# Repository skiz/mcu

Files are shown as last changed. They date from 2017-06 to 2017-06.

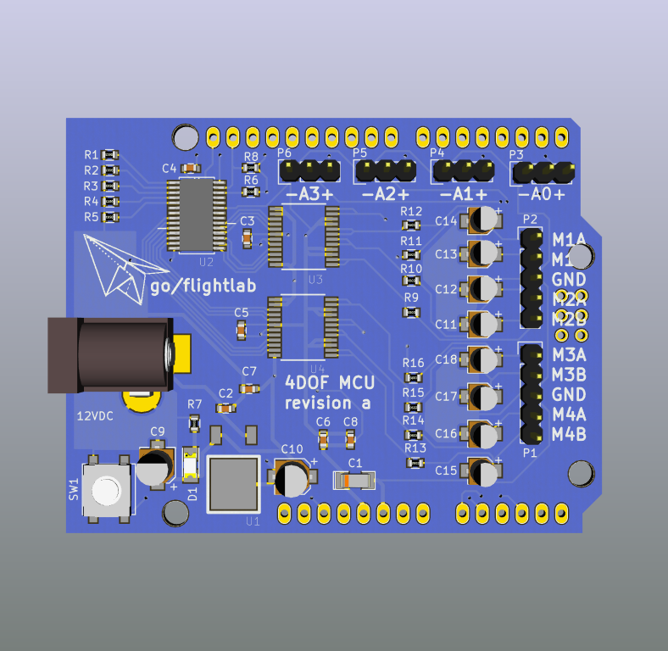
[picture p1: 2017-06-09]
renders/MCU.png

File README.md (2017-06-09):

Motor Control Unit
==================

Overview
--------
This hardware project is based on several existing Arduino boards,
and shields, combining them along with some additional hardware to
provide clean bipolar 10vdc control of up to 3 industrial motor
control units for use with the [SMC3](https://github.com/SimulatorMotorController) 
motion platform software available on Github.

The SMC3 software suite is specifically designed to interact with 
[SimTools](https://www.xsimulator.net/) which generates motion queues
from existing simulator integrations running on Windows.

The schematic, PCB, and related files have been exclusively created in [KiCad](kicad-pcb.org/).

Structure
---------
There are several directories which contain various references for the project;

* board      - The KiCad project itself: PCB, Schematic, etc.
* bom        - Bill of Materials required to assemble the complete PCB.
* datasheets - All datasheets related to the componented used in the design.
* libraries  - Libraries specific to this design (PCB footprints & Symbols).
* models     - 3d models used for rendering the board
* renders    - 2D/3D renderings of the board, and misc images

Parent Hardware
---------------
As this is a culmination of existing OSS hardware, it's only appropriate to
list the "donors" here.  The hardware here basically consists of stripped
down Adafruit Motor Shield V2, and some additional DAC
conversions and voltage regulation for +/-10v analog DC output.

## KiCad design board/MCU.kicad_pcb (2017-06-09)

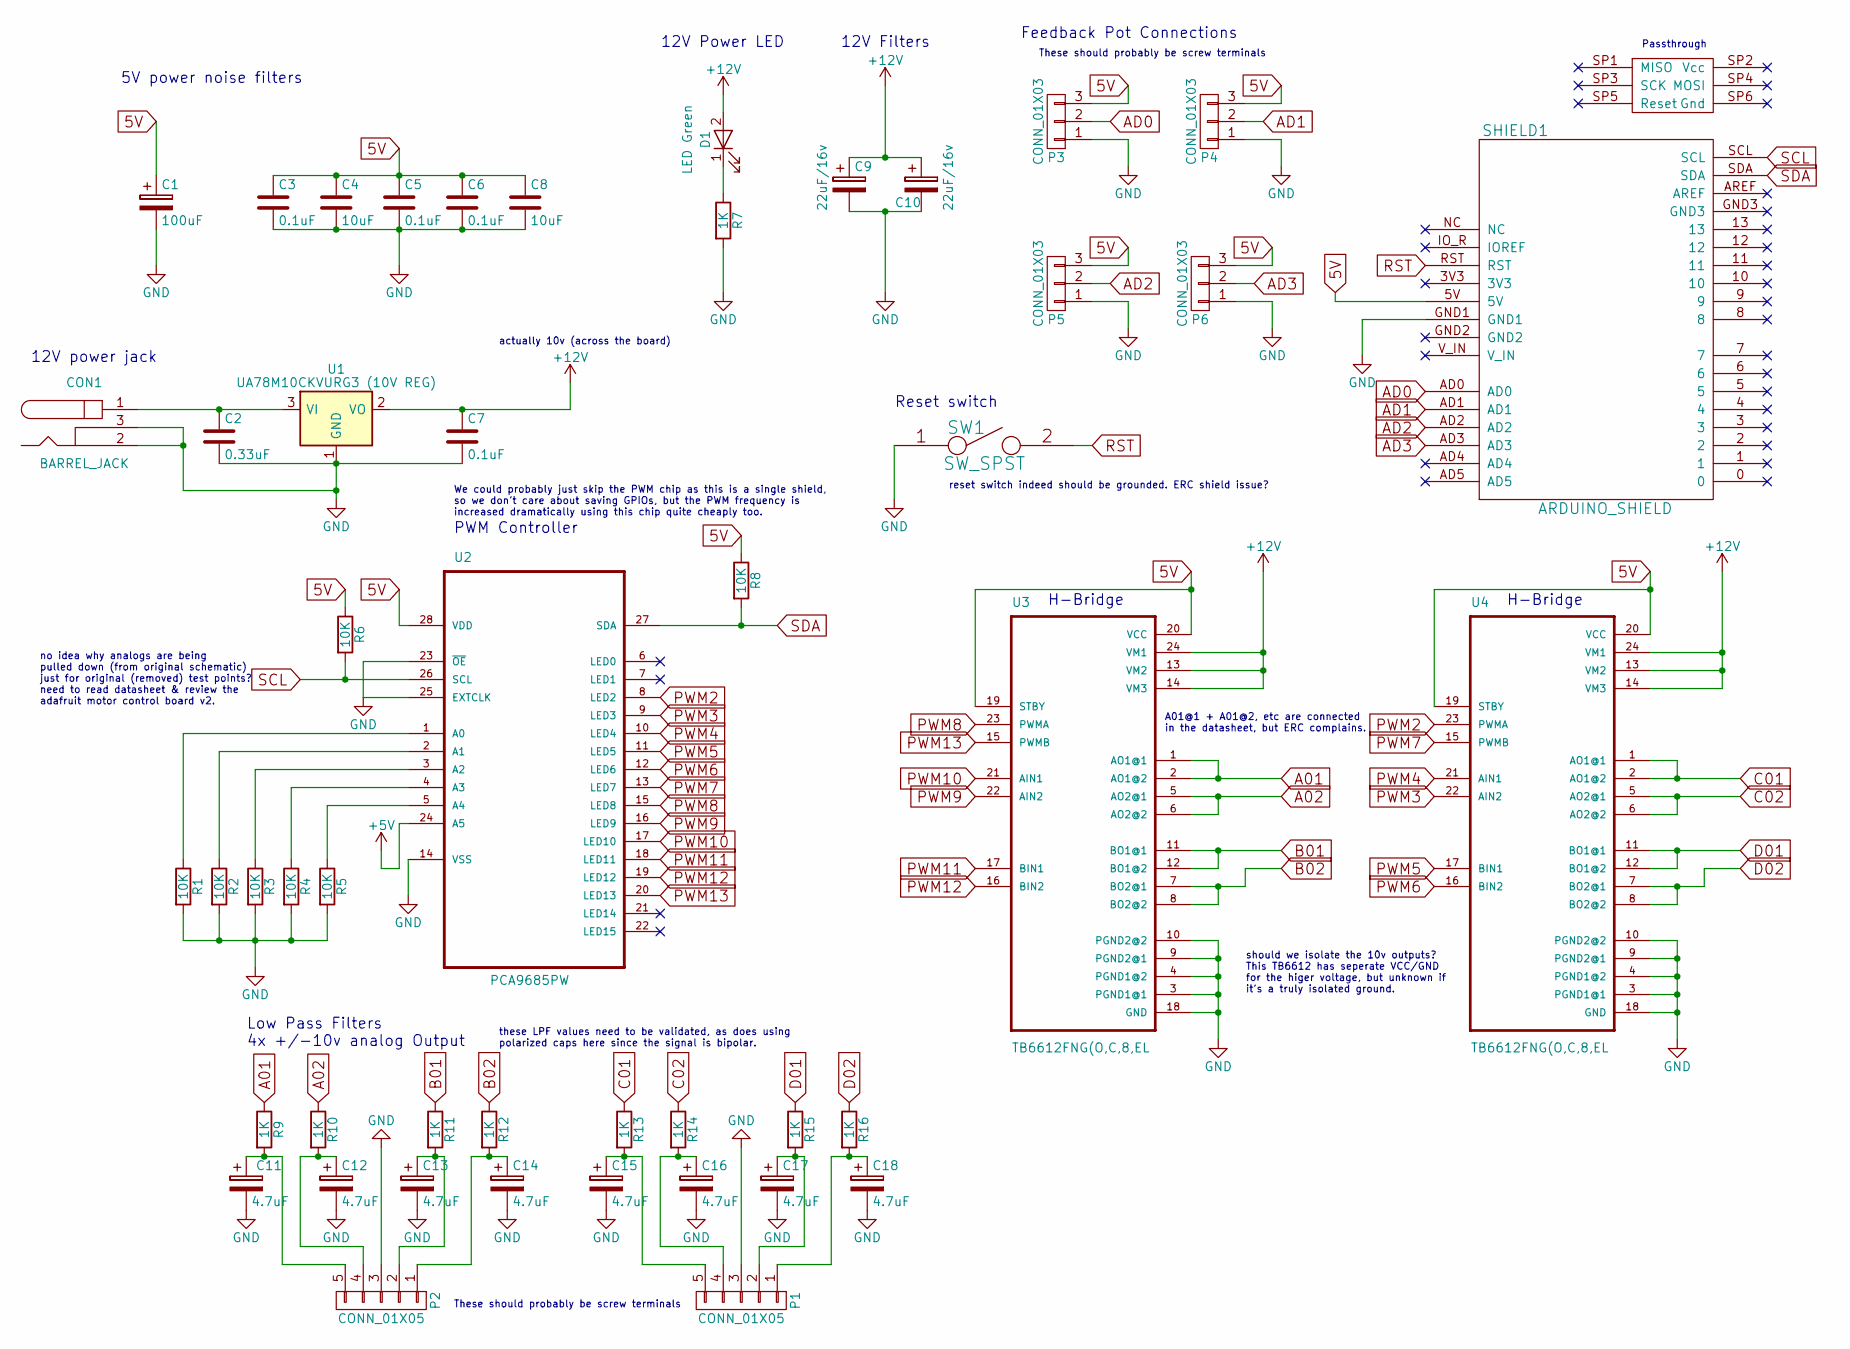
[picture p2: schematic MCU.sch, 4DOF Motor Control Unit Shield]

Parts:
C1: 100uF; SMD-1206_Pol
C2: 0.33uF; C_0603
C3, C5, C6, C7: 0.1uF; C_0603
C4, C8: 10uF; C_0603
C9, C10: 22uF/16v; c_elec_4x5.8
C11, C12, C13, C14, C15, C16, C17, C18: 4.7uF; c_elec_3x5.3
CON1: BARREL_JACK; JACK_ALIM
D1: LED Green; LED_1206
P1, P2: CONN_01X05; Pin_Header_Straight_1x05
P3, P4, P5, P6: CONN_01X03; Pin_Header_Straight_1x03
R1, R2, R3, R4, R5, R6, R8: 10K; R_0603
R7, R9, R10, R11, R12, R13, R14, R15, R16: 1K; R_0603
SHIELD1: ARDUINO_SHIELD
SW1: SW_SPST; SW_SPST_B3SL-1002P
U1: UA78M10CKVURG3 (10V REG); TO-252-3
U2: PCA9685PW; SOP65P640X110-28N
U3, U4: TB6612FNG(O,C,8,EL; SOP65P760X160-24N

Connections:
5V: C1.1, C3.1, C4.1, C5.1, C6.1, C8.1, P3.3, P4.3, P5.3, P6.3, R6.1, R8.1, SHIELD1.5V, U2.28 (VDD), U3.19 (STBY), U3.20 (VCC), U4.19 (STBY), U4.20 (VCC)
+12V: C7.1, C9.1, C10.1, D1.2 (A), U1.2 (VO), U3.13 (VM2), U3.14 (VM3), U3.24 (VM1), U4.13 (VM2), U4.14 (VM3), U4.24 (VM1)
A01: R9.1, U3.1 (AO1@1), U3.2 (AO1@2)
A02: R10.1, U3.5 (AO2@1), U3.6 (AO2@2)
AD0: P3.2, SHIELD1.AD0
AD1: P4.2, SHIELD1.AD1
AD2: P5.2, SHIELD1.AD2
AD3: P6.2, SHIELD1.AD3
B01: R11.1, U3.11 (BO1@1), U3.12 (BO1@2)
B02: R12.1, U3.7 (BO2@1), U3.8 (BO2@2)
C01: R13.1, U4.1 (AO1@1), U4.2 (AO1@2)
C02: R14.1, U4.5 (AO2@1), U4.6 (AO2@2)
D01: R15.1, U4.11 (BO1@1), U4.12 (BO1@2)
D02: R16.1, U4.7 (BO2@1), U4.8 (BO2@2)
GND: C1.2, C2.2, C3.2, C4.2, C5.2, C6.2, C7.2, C8.2, C9.2, C10.2, C11.2, C12.2, C13.2, C14.2, C15.2, C16.2, C17.2, C18.2, CON1.2, CON1.3, P1.3, P2.3, P3.1, P4.1, P5.1, P6.1, R1.2, R2.2, R3.2, R4.2, R5.2, R7.2, SHIELD1.GND1, SW1.1, U1.1 (GND), U2.14 (VSS), U2.23 (~OE), U2.25 (EXTCLK), U3.3 (PGND1@1), U3.4 (PGND1@2), U3.9 (PGND2@1), U3.10 (PGND2@2), U3.18 (GND), U4.3 (PGND1@1), U4.4 (PGND1@2), U4.9 (PGND2@1), U4.10 (PGND2@2), U4.18 (GND); also elsewhere on the board
unnamed 15: C2.1, CON1.1, U1.3 (VI); also elsewhere on the board
unnamed: C11.1, P2.5, R9.2
unnamed: C12.1, P2.4, R10.2
unnamed: C13.1, P2.2, R11.2
unnamed: C14.1, P2.1, R12.2
unnamed: C15.1, P1.5, R13.2
unnamed: C16.1, P1.4, R14.2
unnamed: C17.1, P1.2, R15.2
unnamed: C18.1, P1.1, R16.2
unnamed: D1.1 (K), R7.1
unnamed: R1.1, U2.1 (A0)
unnamed: R2.1, U2.2 (A1)
unnamed: R3.1, U2.3 (A2)
unnamed: R4.1, U2.4 (A3)
unnamed: R5.1, U2.5 (A4)
PWM2: U2.8 (LED2), U4.23 (PWMA)
PWM3: U2.9 (LED3), U4.22 (AIN2)
PWM4: U2.10 (LED4), U4.21 (AIN1)
PWM5: U2.11 (LED5), U4.17 (BIN1)
PWM6: U2.12 (LED6), U4.16 (BIN2)
PWM7: U2.13 (LED7), U4.15 (PWMB)
PWM8: U2.15 (LED8), U3.23 (PWMA)
PWM9: U2.16 (LED9), U3.22 (AIN2)
PWM10: U2.17 (LED10), U3.21 (AIN1)
PWM11: U2.18 (LED11), U3.17 (BIN1)
PWM12: U2.19 (LED12), U3.16 (BIN2)
PWM13: U2.20 (LED13), U3.15 (PWMB)
RST: SHIELD1.RST, SW1.2
SCL: R6.2, SHIELD1.SCL, U2.26 (SCL)
SDA: R8.2, SHIELD1.SDA, U2.27 (SDA)

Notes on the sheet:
Reset switch
12V Power LED
5V power noise filters
PWM Controller
H-Bridge
12V power jack
Feedback Pot Connections
Low Pass Filters 4x +/-10v analog Output
A01@1 + A01@2, etc are connected in the datasheet, but ERC complains.
12V Filters
no idea why analogs are being pulled down (from original schematic) just for original (removed) test points? need to read datasheet & review the adafruit motor control board v2.
should we isolate the 10v outputs? This TB6612 has seperate VCC/GND for the higer voltage, but unknown if it's a truly isolated ground.
actually 10v (across the board)
these LPF values need to be validated, as does using polarized caps here since the signal is bipolar.
We could probably just skip the PWM chip as this is a single shield, so we don't care about saving GPIOs, but the PWM frequency is increased dramatically using this chip quite cheaply too.
These should probably be screw terminals
reset switch indeed should be grounded. ERC shield issue?
Passthrough

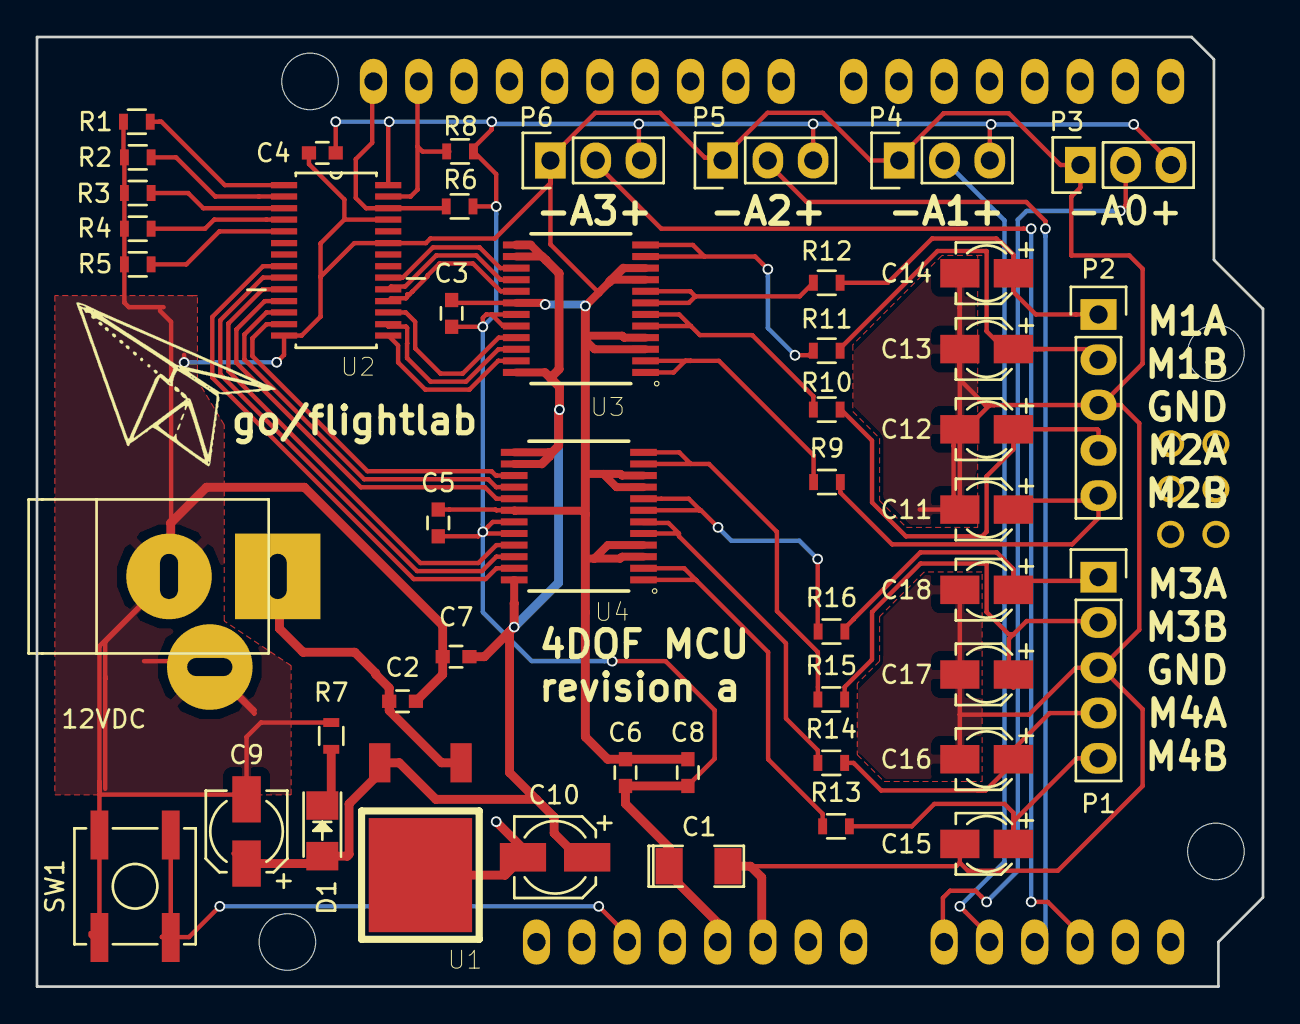
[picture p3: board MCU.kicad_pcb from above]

Board: 2 copper layers, 68.8 x 53.2 mm, 48 parts (0 on the bottom side), 45 nets.

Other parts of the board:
12VDC: BARREL_JACK; JACK_ALIM

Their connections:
GND: 12VDC.2, 12VDC.3; also elsewhere on the board
unnamed 15: 12VDC.1; also elsewhere on the board
